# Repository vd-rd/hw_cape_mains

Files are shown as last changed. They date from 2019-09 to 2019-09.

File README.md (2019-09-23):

## Overview
 Isolated mains supply module designed to power IoT projects that have a <15W power requirement. It is designed around readily available step-down power modules with additional filtering to ensure compliance to standard specifications.

### Specifications

Two versions of the board are available, depending on the choice of the module:
 * MeanWell IRM 
 * Aimtec AMEOF 

In both cases the boards feature:
 * 85-240V input
 * 15W output at 12V
 * 5V regulated output using an LDO
 * Current sensor for measuring board consumption
 * IEC-C6 power connector
The board has a small footprint (80x40x25mm) with the power connector protruding an additional 3mm at the edge.

### Resources
You can find all necesary information to build or evaluate the module here:
   - [View layout and schematic](https://cadlab.io/project/) 
   - [View 3D board render](https://a360.co/2V6xbaF)
   - [Fabrication files](https://github.com/vd-rd/hw_cape_mains/releases)

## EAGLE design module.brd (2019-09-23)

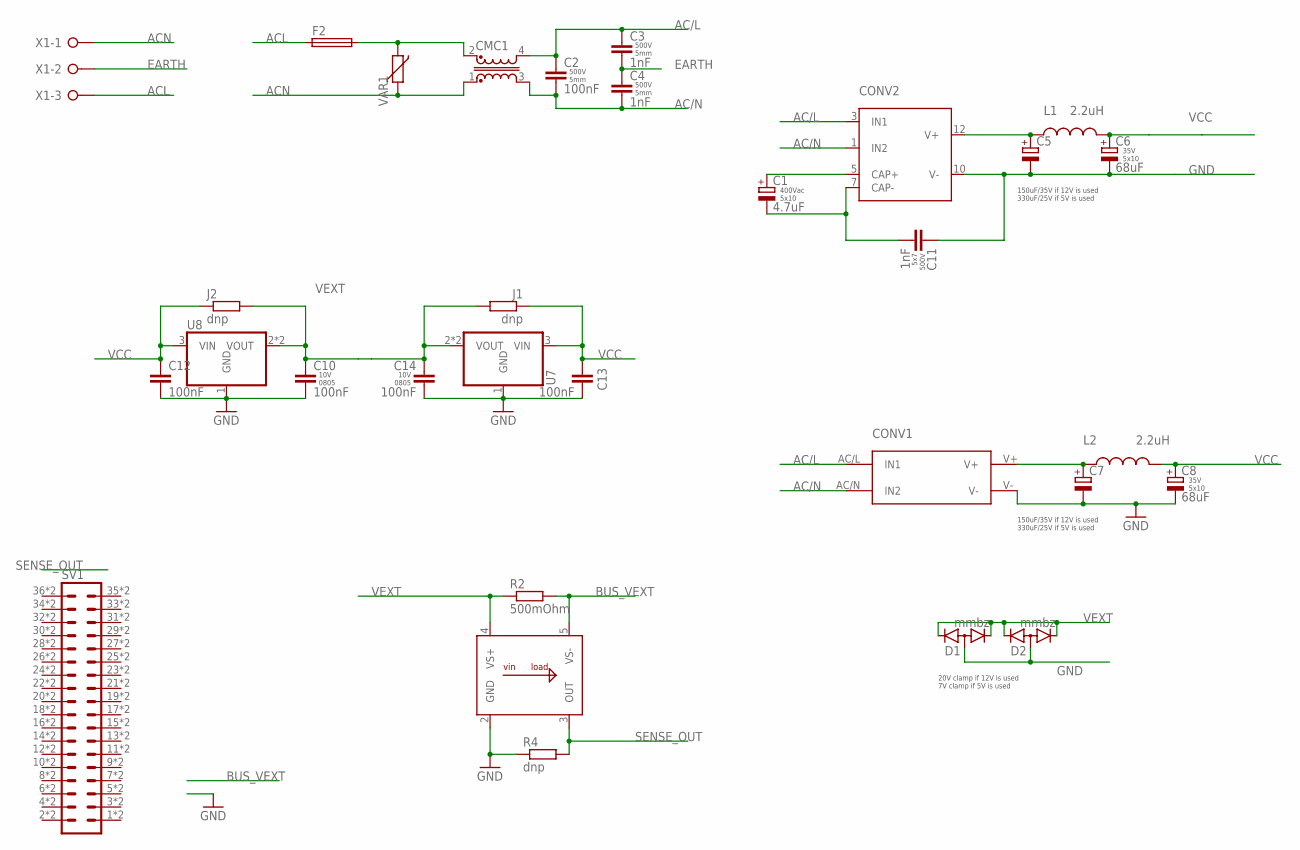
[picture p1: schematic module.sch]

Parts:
C1: 4.7uF; CAPPRD508W65D1000H1600B; RATING 400Vac
C2: 100nF; C050-025X075; RATING 500V
C3, C4: 1nF; C050-025X075; RATING 500V
C5, C7: CAP-POL-5PX10WX16H; CAPPRD508W65D1000H1600B
C6, C8: 68uF; CAPPRD508W65D1000H1600B; RATING 35V
C10, C12, C13, C14: 100nF; C0805
C11: 1nF; C050-025X075
CMC1: DLD-302U-1A; DLD
CONV1: IRM-03-12V; IRM-03
CONV2: AMEOF312SJZ; AMEOF3-JZ
D1, D2: mmbz; SOT23
F2: ZH8; ZH8X2
IC1: ZXCT1021; SOT95P240X110-5
J1, J2: dnp; R0805
L1, L2: 2.2uH; COIL0608
R2: 500mOhm; R0805
R4: dnp; R0603
SV1: MA18-2SMT; MA18-2-SMT
U7, U8: LD1117S50; SOT230P700X180-4
VAR1: S14K250; C7.5B4
X1: W237-03P; W237-133

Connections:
AC/L: C2.1, C3.1, CMC1.4, CONV1.AC/L (IN1), CONV2.3 (IN1)
AC/N: C2.2, C4.2, CMC1.3, CONV1.AC/N (IN2), CONV2.1 (IN2)
ACL: F2.1, F2.1A (1), X1.3
ACN: CMC1.1, VAR1.1, X1.1
BUS_VEXT: IC1.5 (VS-), R2.2
EARTH: C3.2, C4.1, X1.2
GND: C5.2 (-), C6.2 (-), C7.2 (-), C8.2 (-), C10.2, C11.1, C12.2, C13.2, C14.2, CONV1.V-, CONV2.10 (V-), D1.3 (A), D2.3 (A), IC1.2 (GND), R4.1, U7.1 (GND), U8.1 (GND)
unnamed: C1.1 (+), CONV2.5 (CAP+)
unnamed: C1.2 (-), C11.2, CONV2.7 (CAP-)
unnamed: C5.1 (+), CONV2.12 (V+), L1.P$1 (1)
unnamed: CMC1.2, F2.2, F2.2A (2), VAR1.2
unnamed: C7.1 (+), CONV1.V+, L2.P$1 (1)
SENSE_OUT: IC1.3 (OUT), R4.2
VCC: C6.1 (+), C8.1 (+), C12.1, C13.1, J1.1, J2.1, L1.P$2 (2), L2.P$2 (2), U7.3 (VIN), U8.3 (VIN)
VEXT: C10.1, C14.1, D1.1 (K1), D1.2 (K2), D2.1 (K1), D2.2 (K2), IC1.4 (VS+), J1.2, J2.2, R2.1, U7.2 (VOUT), U7.4 (VOUT), U8.2 (VOUT), U8.4 (VOUT)

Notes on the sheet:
150uF/35V if 12V is used 330uF/25V if 5V is used
20V clamp if 12V is used 7V clamp if 5V is used

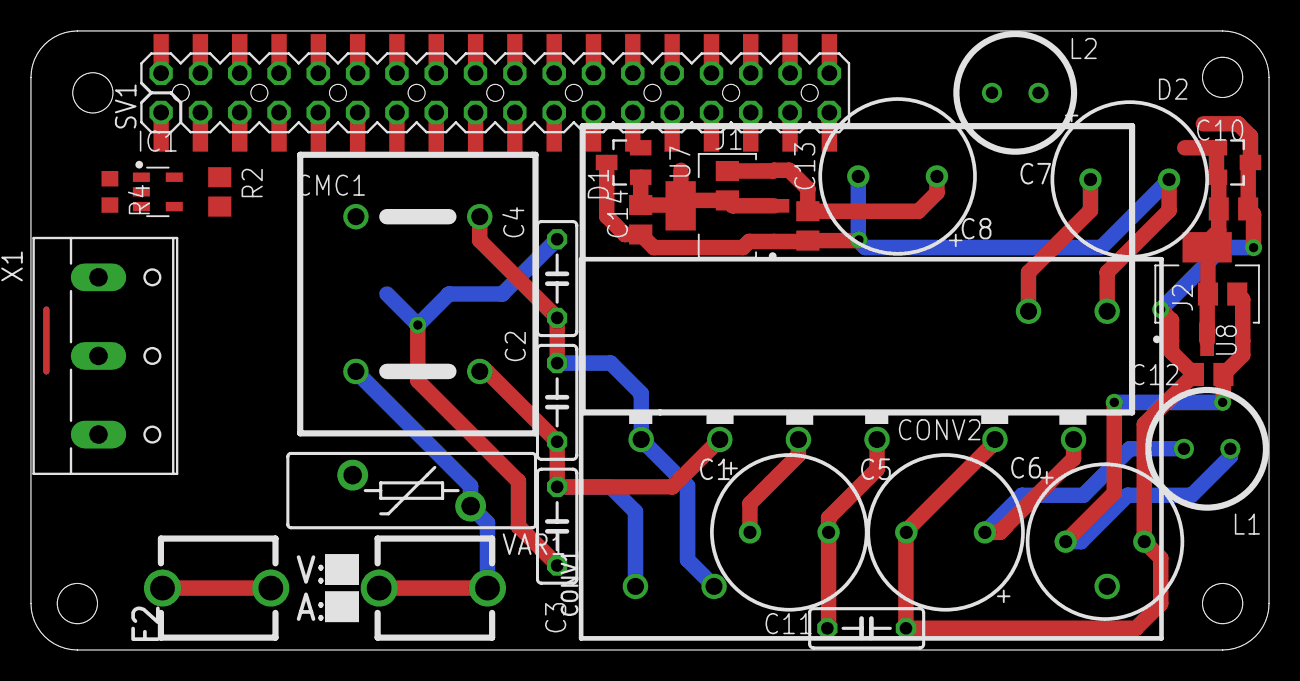
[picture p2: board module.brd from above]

Board: 2 copper layers, 80.0 x 40.0 mm, 31 parts (0 on the bottom side), 15 nets.

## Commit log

2018-12-26 board bringup
    [v0.1.0.brd, v0.1.0.sch]
2019-01-17 added assembly variants
    [v0.2.0.brd, v0.2.0.sch, v0.3.0.brd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]
2019-01-17 defined connections
    [v0.3.0.brd, v0.3.0.sch]
2019-01-17 polished schematic
    [v0.3.1.brd, v0.3.1.sch]
2019-01-17 added identification prints
    [v0.3.1.brd]
2019-01-17 added logo
    [v0.3.2.brd, v0.3.2.sch]
2019-01-17 minor fixes
    [v0.3.2.brd]
2019-03-12 cosmetic fixes
    [v0.3.2.brd]
2019-05-02 project: update structure
    [module.brd, module.sch, v0.1.0.brd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]
2019-05-02 layout: minor routing changes
    [module.brd]
2019-09-23 project: remove logo and add new connector
    [module.brd, module.sch]
2019-09-23 project: add new connector for embedded apps
    [module.brd, module.sch]
